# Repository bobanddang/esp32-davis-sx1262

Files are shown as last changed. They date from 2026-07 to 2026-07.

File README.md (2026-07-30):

# ESP32 Davis SX1262 Weather Bridge

Capture wireless ISS telemetry from a **Davis Vantage Pro2 / Vue** station with an ESP32 (S3/C3/C5) and **Waveshare Core1262-HF** (Semtech SX1262), then publish decoded metrics to **Home Assistant** via MQTT Auto-Discovery.

Others have already done the hard work of reverse-engineering the Davis FHSS hop tables, packet layout, and CRC — notably projects such as [DavisRFM69](https://github.com/dekay/DavisRFM69) (and related community efforts around RFM69 / SDR reception). Those implementations target different radios. This repository exists to bring that same protocol knowledge to the **SX1262 / Core1262-HF** path and wire it into Home Assistant. Huge thanks to those authors for the heavy lifting; this project stands on their shoulders.

## Hardware wiring

| Core1262-HF | ESP32-S3 | ESP32-C3 | ESP32-C5 | Notes |
|---|---|---|---|---|
| SCK | 12 | 6 | 6 | FSPI / SPI2_HOST |
| MISO | 13 | 2 | 2 | |
| MOSI | 11 | 7 | 7 | |
| NSS (CS) | 10 | 10 | 10 | |
| RST | 14 | 3 | 3 | |
| BUSY | 8 | 4 | 4 | |
| DIO1 | 9 | 5 | 5 | Packet IRQ |
| RXEN | 3.3V | 3.3V | 3.3V | Or use `setDio2AsRfSwitch(true)` |
| 3V3 / GND | 3V3/GND  | 3V3/GND  | 3V3/GND  | |

C3/C5 share the SPI2 IO_MUX defaults (flash uses different pins than S3). On Waveshare **ESP32-C5-Zero**, GPIOs 2–7 and 10 are all on the side headers. `pins.h` selects the map from `CONFIG_IDF_TARGET_*`.

## Setup

1. Install [PlatformIO](https://platformio.org/).
2. Copy `secrets.ini.example` → `secrets.ini` and set Wi-Fi / MQTT flags (file is gitignored).
3. Build & flash (S3 default; C3/C5 envs available):
   ```bash
   pio run -e esp32-s3-devkitc1-n16r8 -t upload
   # pio run -e esp32-c3-devkitm-1 -t upload
   # pio run -e esp32-c5-devkitc1-n4 -t upload   # Waveshare ESP32-C5-Zero (4MB)
   pio device monitor
   ```

`DAVIS_STATION_ID` must match the DIP/switch ID on the ISS (0–7). Hop interval is `2562.5 ms + ID × 62.5 ms`.

## MQTT topics

| Topic | Purpose |
|---|---|
| `homeassistant/sensor/davis_weather/<name>/config` | HA Auto-Discovery (retained) |
| `homeassistant/sensor/davis_weather/state` | JSON telemetry |
| `homeassistant/sensor/davis_weather/status` | `online` / `offline` |

Device identifier: `davis_vantage_pro2` (single HA device “Davis Weather Station”).

### State JSON fields

`temperature_f`, `humidity_pct`, `wind_mph`, `wind_gust_mph`, `wind_dir_deg`, `rain_rate_in_hr`, `rain_tips`, `rain_accum_in`, `solar_wm2`, `uv_index`, `battery_low`, `station_id`, `rssi_dbm`, `channel`

## Architecture

| Module | Role |
|---|---|
| `DavisHopper` | 51-channel US FHSS state machine; Lost Sync → continuous RX on ch 0 after 4 missed hops |
| `DavisDecode` | Bit-reverse, CCITT CRC-16, packet-type field extraction |
| `MqttManager` | Wi-Fi, PubSubClient, HA discovery + state publish |
| `main.cpp` | SPI bring-up, non-blocking `loop()` |

### Radio (GFSK)

- 19.2 kbps, ±9.6 kHz deviation, 156.2 kHz RX BW  
- Preamble: 4 × `0xAA`  
- Sync: `0xCB 0x89`  
- `setDio2AsRfSwitch(true)`, `setTCXO(1.6)` for Core1262-HF  

Hop frequencies use the DavisRFM69 North America FRF table (~902–928 MHz).

## Notes

- US ISS tip size defaults to **0.01 in/tip** (`DAVIS_RAIN_INCHES_PER_TIP`).
- EU 868 MHz stations need a different hop table (not enabled in this build).
- If acquisition is weak outdoors, try widening RX BW to `234.3` or `467.0` in `DavisHopper.h`.

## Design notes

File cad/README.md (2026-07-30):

# Enclosure (FreeCAD)

Minimal FreeCAD model for a small box that fits this project when built with the **same hardware** used for the working ESP32-C3 + Waveshare Core1262-HF setup.

It is intentionally simple: a shell and a plate sized for that stack, not a universal case for every ESP32 variant.

## Files

| File | Description |
|---|---|
| `davis-relay.FCStd` | FreeCAD source |
| `davis-relay-shell.step` | Enclosure shell (STEP) |
| `davis-relay-plate.step` | Mounting / lid plate (STEP) |
| `davis-relay-plate.3mf` | Plate export for 3D printing |

Open `davis-relay.FCStd` in [FreeCAD](https://www.freecad.org/) to tweak dimensions.

## Hardware this box was designed around

These are affiliate links — I get a little money if you buy through them. Almost any similar parts should work. I also tested with an ESP32-S3 and ESP32-C5; both worked fine when wired to the pins in the main README.

- ESP32-C3 board: https://amzn.to/4hbI4Rr
- Waveshare Core1262-HF (SX1262): https://amzn.to/3RHByar (white-label version of the Waveshare board)
- ElectroCookie proto board: https://amzn.to/3S5fS8v (standoffs fit this specific board)
- Heat-set inserts: https://amzn.to/4pLMBvY (I used inserts from this kit; others should work, but the holes are fairly narrow, so you need thin-walled M3 inserts. Frankly the columns should be wider, but there isn’t much torque on these.)
- Antenna and U.FL-to-SMA adapter: https://amzn.to/4pQ1LjY (I used this; almost anything should work depending on how far you are from the weather station. Never power the radio on without an antenna connected.)

If you use a different MCU (S3/C5 Zero, etc.) or a taller antenna / different header stack-up, expect to edit the model.

## Notes

- Print orientation and clearances are up to you; verify fit before committing to a final print.
- Cable / antenna cutouts may need adjusting for your wiring and U.FL vs ceramic antenna choice.

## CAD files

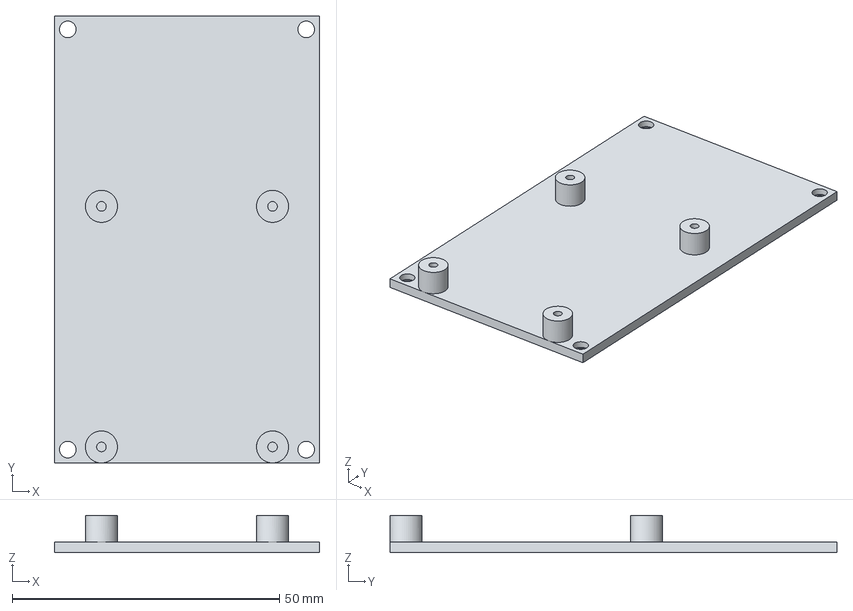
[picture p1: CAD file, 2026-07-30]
cad/davis-relay-plate.step
49.6 x 83.6 x 7.00 mm

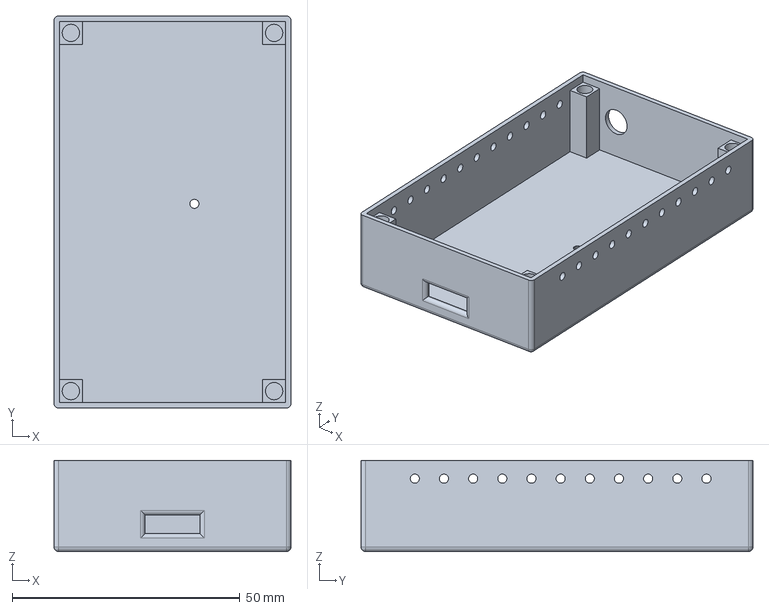
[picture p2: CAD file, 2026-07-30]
cad/davis-relay.FCStd
52.0 x 86.0 x 20.0 mm

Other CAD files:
cad/davis-relay-shell.step
cad/davis-relay-plate.3mf

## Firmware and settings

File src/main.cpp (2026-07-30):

#include <Arduino.h>
#include <RadioLib.h>
#include <SPI.h>

#include "Config.h"
#include "DavisDecode.h"
#include "DavisHopper.h"
#include "MqttManager.h"
#include "pins.h"

// FSPI (SPI2_HOST) dedicated to the Core1262-HF
SPIClass radioSPI(FSPI);

SX1262 radio = new Module(PIN_RADIO_CS, PIN_RADIO_DIO1, PIN_RADIO_RST,
                          PIN_RADIO_BUSY, radioSPI,
                          RADIOLIB_DEFAULT_SPI_SETTINGS);

DavisHopper hopper(radio);
MqttManager mqtt;

DavisDecode::WeatherData weather;
volatile bool weatherDirty = false;
int16_t lastRssi = 0;

void onDavisPacket(const uint8_t* decoded,
                   const DavisDecode::PacketFields& /*fields*/, int16_t rssi,
                   float /*snr*/, void* /*ctx*/) {
  DavisDecode::applyPacket(decoded, weather, DAVIS_RAIN_INCHES_PER_TIP);
  lastRssi = rssi;
  weatherDirty = true;
}

void setup() {
  Serial.begin(115200);
  // USB CDC can take a moment after reset; don't block forever if monitor is late.
  const uint32_t serialWaitUntil = millis() + 2000;
  while (!Serial && millis() < serialWaitUntil) {
    delay(10);
  }
  delay(200);
  Serial.println();
  Serial.println(F("esp32-davis-sx1262"));
  Serial.println(F("Davis Vantage Pro2/Vue → MQTT / Home Assistant"));
  Serial.flush();

#if defined(CONFIG_IDF_TARGET_ESP32C5)
  // Waveshare ESP32-C5-Zero RF switch: LOW = ceramic, HIGH = U.FL
  pinMode(26, OUTPUT);
  digitalWrite(26, LOW);
  Serial.println(F("[main] C5-Zero antenna=onboard (IO26 LOW)"));
#endif

  radioSPI.begin(PIN_SPI_SCK, PIN_SPI_MISO, PIN_SPI_MOSI, -1);

  hopper.setPacketCallback(onDavisPacket);
  if (!hopper.begin(DAVIS_STATION_ID)) {
    Serial.println(F("[main] radio init failed — halt"));
    while (true) {
      delay(1000);
    }
  }

  mqtt.begin();
}

void loop() {
  // Time-critical FHSS engine
  hopper.poll();

  // Wi-Fi / MQTT reconnect (non-blocking)
  mqtt.poll();

  if (weatherDirty) {
    weatherDirty = false;
    mqtt.publishState(weather, lastRssi, hopper.lastRxChannel());
  }
}

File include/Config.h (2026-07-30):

#pragma once

// Wi-Fi / MQTT credentials. Set via gitignored secrets.ini build_flags.
#ifndef WIFI_SSID
#define WIFI_SSID "YOUR_WIFI_SSID"
#endif

#ifndef WIFI_PASSWORD
#define WIFI_PASSWORD "YOUR_WIFI_PASSWORD"
#endif

#ifndef MQTT_HOST
#define MQTT_HOST "homeassistant.local"
#endif

#ifndef MQTT_PORT
#define MQTT_PORT 1883
#endif

#ifndef MQTT_USER
#define MQTT_USER ""
#endif

#ifndef MQTT_PASSWORD
#define MQTT_PASSWORD ""
#endif

// Davis transmitter ID (0–7). Hop interval grows by 62.5 ms per ID step.
#ifndef DAVIS_STATION_ID
#define DAVIS_STATION_ID 0
#endif

// Rain tip size: 0.01" (US) or 0.2 mm (metric/EU tippers often use 0.2 mm).
#ifndef DAVIS_RAIN_INCHES_PER_TIP
#define DAVIS_RAIN_INCHES_PER_TIP 0.01f
#endif

#define MQTT_CLIENT_ID        "esp32_davis_sx1262"
#define HA_DEVICE_NAME        "Davis Weather Station"
#define HA_DEVICE_ID          "davis_vantage_pro2"
#define HA_DISCOVERY_PREFIX   "homeassistant"
#define HA_STATE_TOPIC        "homeassistant/sensor/davis_weather/state"

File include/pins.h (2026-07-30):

#pragma once

// Waveshare Core1262-HF SPI + control pins.
// C3/C5: use SPI2 IO_MUX defaults (flash occupies other GPIOs than on S3).

#if defined(CONFIG_IDF_TARGET_ESP32C3) || defined(CONFIG_IDF_TARGET_ESP32C5)
// ESP32-C3 / ESP32-C5 — SPI2 dedicated pins (also fit Waveshare C5-Zero headers)
#define PIN_RADIO_CS    10
#define PIN_RADIO_DIO1  5
#define PIN_RADIO_RST   3
#define PIN_RADIO_BUSY  4

#define PIN_SPI_MOSI    7
#define PIN_SPI_MISO    2
#define PIN_SPI_SCK     6
#else
// ESP32-S3 DevKit (Lonely Binary / similar) — FSPI / SPI2_HOST
#define PIN_RADIO_CS    10
#define PIN_RADIO_DIO1  9
#define PIN_RADIO_RST   14
#define PIN_RADIO_BUSY  8

#define PIN_SPI_MOSI    11
#define PIN_SPI_MISO    13
#define PIN_SPI_SCK     12
#endif

// RXEN tied to 3.3V (or driven by SX1262 DIO2 RF-switch command)

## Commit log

2026-07-30 Initial public release: ESP32 Davis ISS receiver with MQTT Auto-Discovery.
    Capture Vantage Pro2/Vue FHSS packets via SX1262 (RadioLib) and publish
    Home Assistant sensors over Wi-Fi/MQTT. Supports ESP32-S3, C3, and C5.
2026-07-30 Simple box using Freecad
    [davis-relay-plate.3mf, davis-relay-plate.step, davis-relay-shell.step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]
